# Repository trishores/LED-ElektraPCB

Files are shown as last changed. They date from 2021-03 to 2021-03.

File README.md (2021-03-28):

# ElektraPCB

Kicad Capture/Layout project files for the Elektra LED development board.

**Licensing info**

Copyright 2018-2021 ledmaker.org

ElektraPCB is free software: you can redistribute it and/or modify it under the terms of the GNU General Public License as published by the Free Software Foundation, either version 3 of the License, or any later version.

ElektraPCB is distributed in the hope that it will be useful, but WITHOUT ANY WARRANTY; without even the implied warranty of MERCHANTABILITY or FITNESS FOR A PARTICULAR PURPOSE. See the GNU General Public License for more details.

You should have received a copy of the GNU General Public License along with ElektraPCB. If not, see https://www.gnu.org/licenses/.

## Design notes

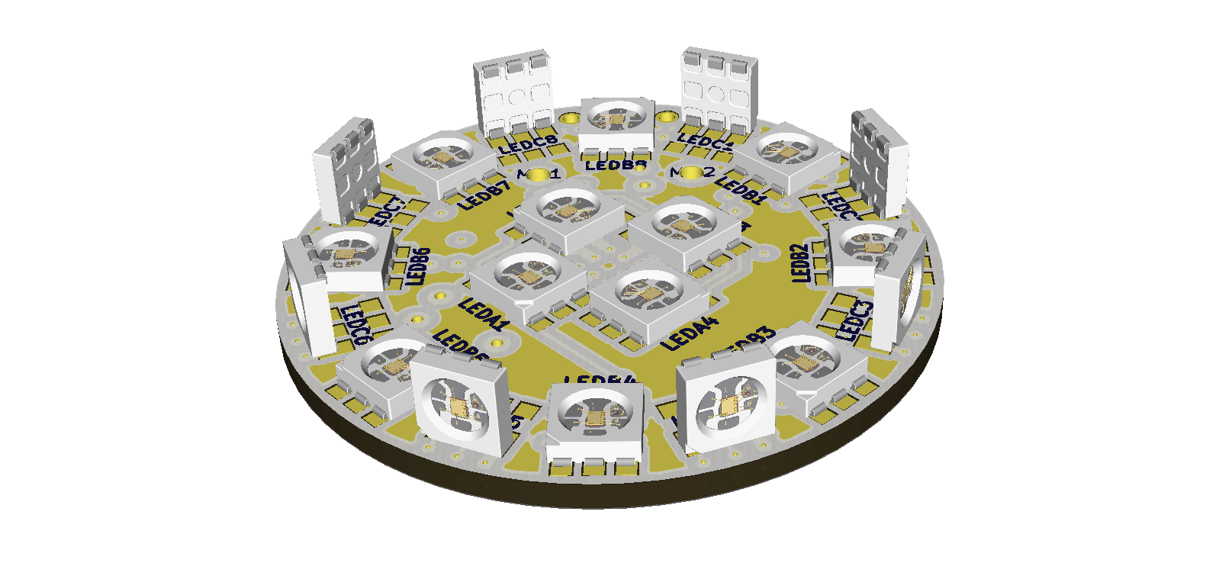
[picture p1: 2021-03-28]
Kicad/disc-front.png

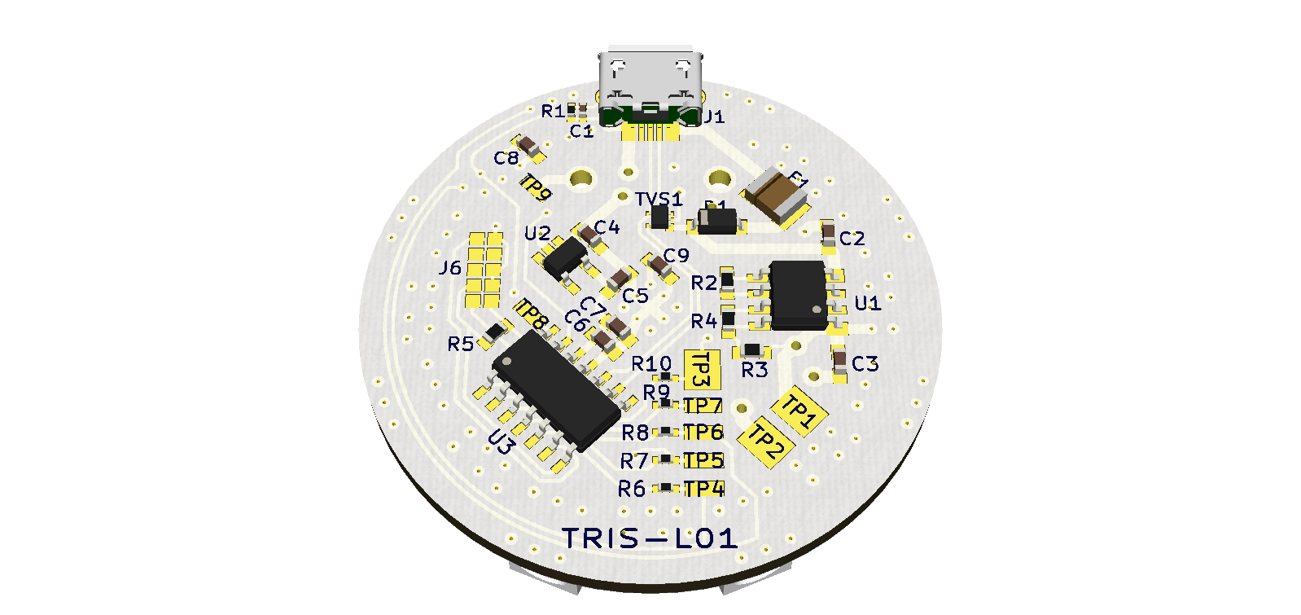
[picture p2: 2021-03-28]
Kicad/disc-back.png

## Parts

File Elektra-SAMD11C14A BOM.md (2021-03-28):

# Elektra-SAMD11C14A development board parts list

| PCB part designators | Quantity | Digikey PN | Manufacturer PN |
| ---| --- | --- | --- |
| J1 | 1 | 609-4616-1-ND | 10118193-0001LF |
| D2 | 1 | SMA6J11AHR3GCT-ND | SMA6J11AHR3G |
| F1 | 1 | 507-1787-1-ND | 0ZCH0075FF2G |
| D1 | 1 | APD240KDTR-G1DICT-ND | APD240KDTR-G1 |
| TVS1 | 1 | NUP2114UPXV5T1GOSCT-ND | NUP2114UPXV5T1G |
| C1* | 1 | 311-1680-1-ND | CC0402JRX7R9BB472 |
| R1* | 1 | 311-1.00MLRCT-ND | RC0402FR-071ML |
| U1 | 1 | 497-17854-1-ND | LDL212DR |
| C2, C3, C4, C5, C7, C8, C9 | 7 | 587-1785-1-ND | JMK107BJ475KA-T |
| R4 | 1 | RR08P22.0KDCT-ND | RR0816P-223-D |
| R2, R3 | 2 | RR08P62.0KDCT-ND | RR0816P-623-D |
| U2 | 1 | MCP1754T-3302E/OTCT-ND | MCP1754T-3302E/OT |
| LEDxx | 20 | - | APA102C** |
| U3 | 1 | ATSAMD11C14A-SSUT | ATSAMD11C14A-SSUT |
| C6 | 1 | 311-1338-1-ND | CC0402KRX7R7BB104 |
| R5 | 1 | 311-1.00KLRCT-ND | RC0402FR-071KL |
| R6, R7, R8, R9, R10 | 5 | P330LCT-ND | ERJ-2RKF3300X |
| J2 | 1 | 952-3577-ND | M50-3030542 |
| Programmer/Debugger | 1 | ATATMEL-ICE-BASIC-ND | ATATMEL-ICE-BASIC |

\* Optional for added protection against noise and transients.

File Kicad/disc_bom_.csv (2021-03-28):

Part | References | Value | Footprint | Quantity
1276-1444-1-ND | C10 | 1uF | C_0402_HandSoldering | 1
311-1.00KLRCT-ND | R5 | 1K | R_0603_HandSoldering | 1
311-1338-1-ND | C6 C11 | 100nF | C_0402_HandSoldering | 2
497-17854-1-ND | U1 | ~ | SOIC-8-LARGE-PADS | 1
507-1787-1-ND | F1 | ~ | F_1210_HandSoldering | 1
587-1785-1-ND | C2 C3 C4 C5 C7 C8 C9 | 4.7uF | C_0603_HandSoldering | 7
609-4616-1-ND | J1 | ~ | USB_Micro_10118193-0001LF-NOPADS | 1
APD240KDTR-G1DICT-ND | D1 | ~ | D_SOD-123 | 1
ATSAMD21E17A-AUTCT-ND | U3 | ATSAMD21E | TQFP-32_7x7mm | 1
952-3577-ND | M50-3030542 | CONN-1x5 | CONN-050-1x5-TH | 1
MCP1754T-3302E/OTCT-ND | U2 | ~ | SOT-23-5_HandSoldering | 1
NUP2114UPXV5T1GOSCT-ND | TVS1 | ~ | SOT-553-LARGE-PADS | 1
P330LCT-ND | R6 R7 R8 R9 R10 | 330 | R_0402_HandSoldering | 5
RR08P22.0KDCT-ND | R4 | 22K | R_0603_HandSoldering | 1
RR08P62.0KDCT-ND | R2 R3 | 62K | R_0603_HandSoldering | 2
SMA6J11AHR3GCT-ND | D2 | SMA6J11A | DO214AC | 1

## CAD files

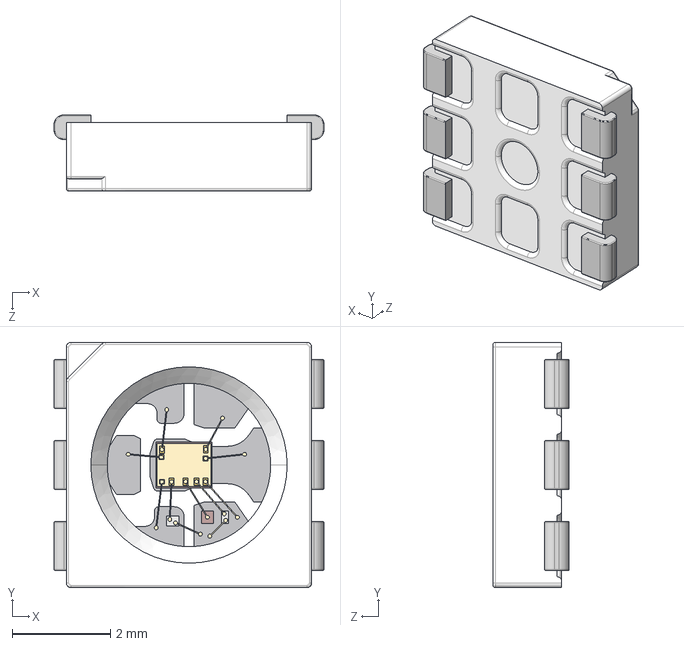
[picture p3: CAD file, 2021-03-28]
a-3d-models/disc-3d/5050/5050.STEP
5.50 x 5.00 x 1.55 mm

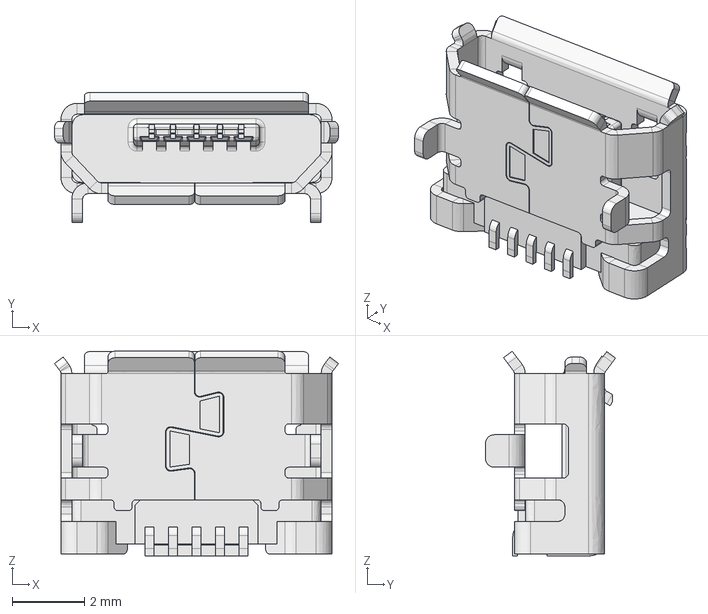
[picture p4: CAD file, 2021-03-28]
a-3d-models/disc-3d/USB_10118193-0001LF/USB_Micro2.FCStd
7.86 x 3.60 x 5.66 mm

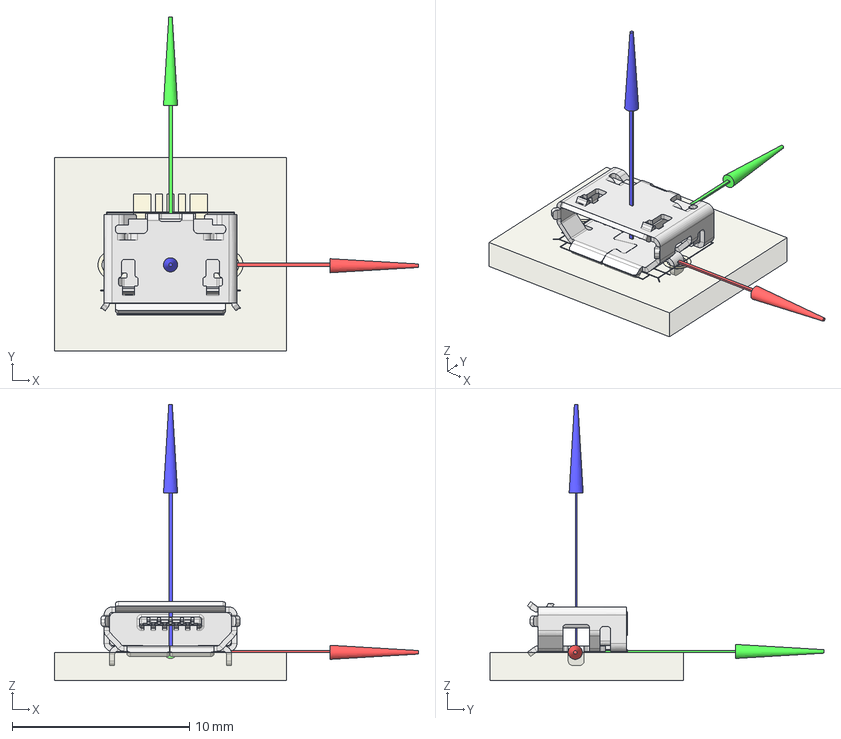
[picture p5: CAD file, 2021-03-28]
a-3d-models/disc-3d/USB_10118193-0001LF/usb_micro.FCStd
20.6 x 18.9 x 15.6 mm
FCrtYd
FFab
TopPads
BotPads
PTHs
Pcb
Z
Y
X
A4A0504-MODIFY-1106_ASM

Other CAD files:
a-3d-models/disc-3d/5050/5050-RA.step
a-3d-models/disc-3d/USB_10118193-0001LF/USB_Micro.stl

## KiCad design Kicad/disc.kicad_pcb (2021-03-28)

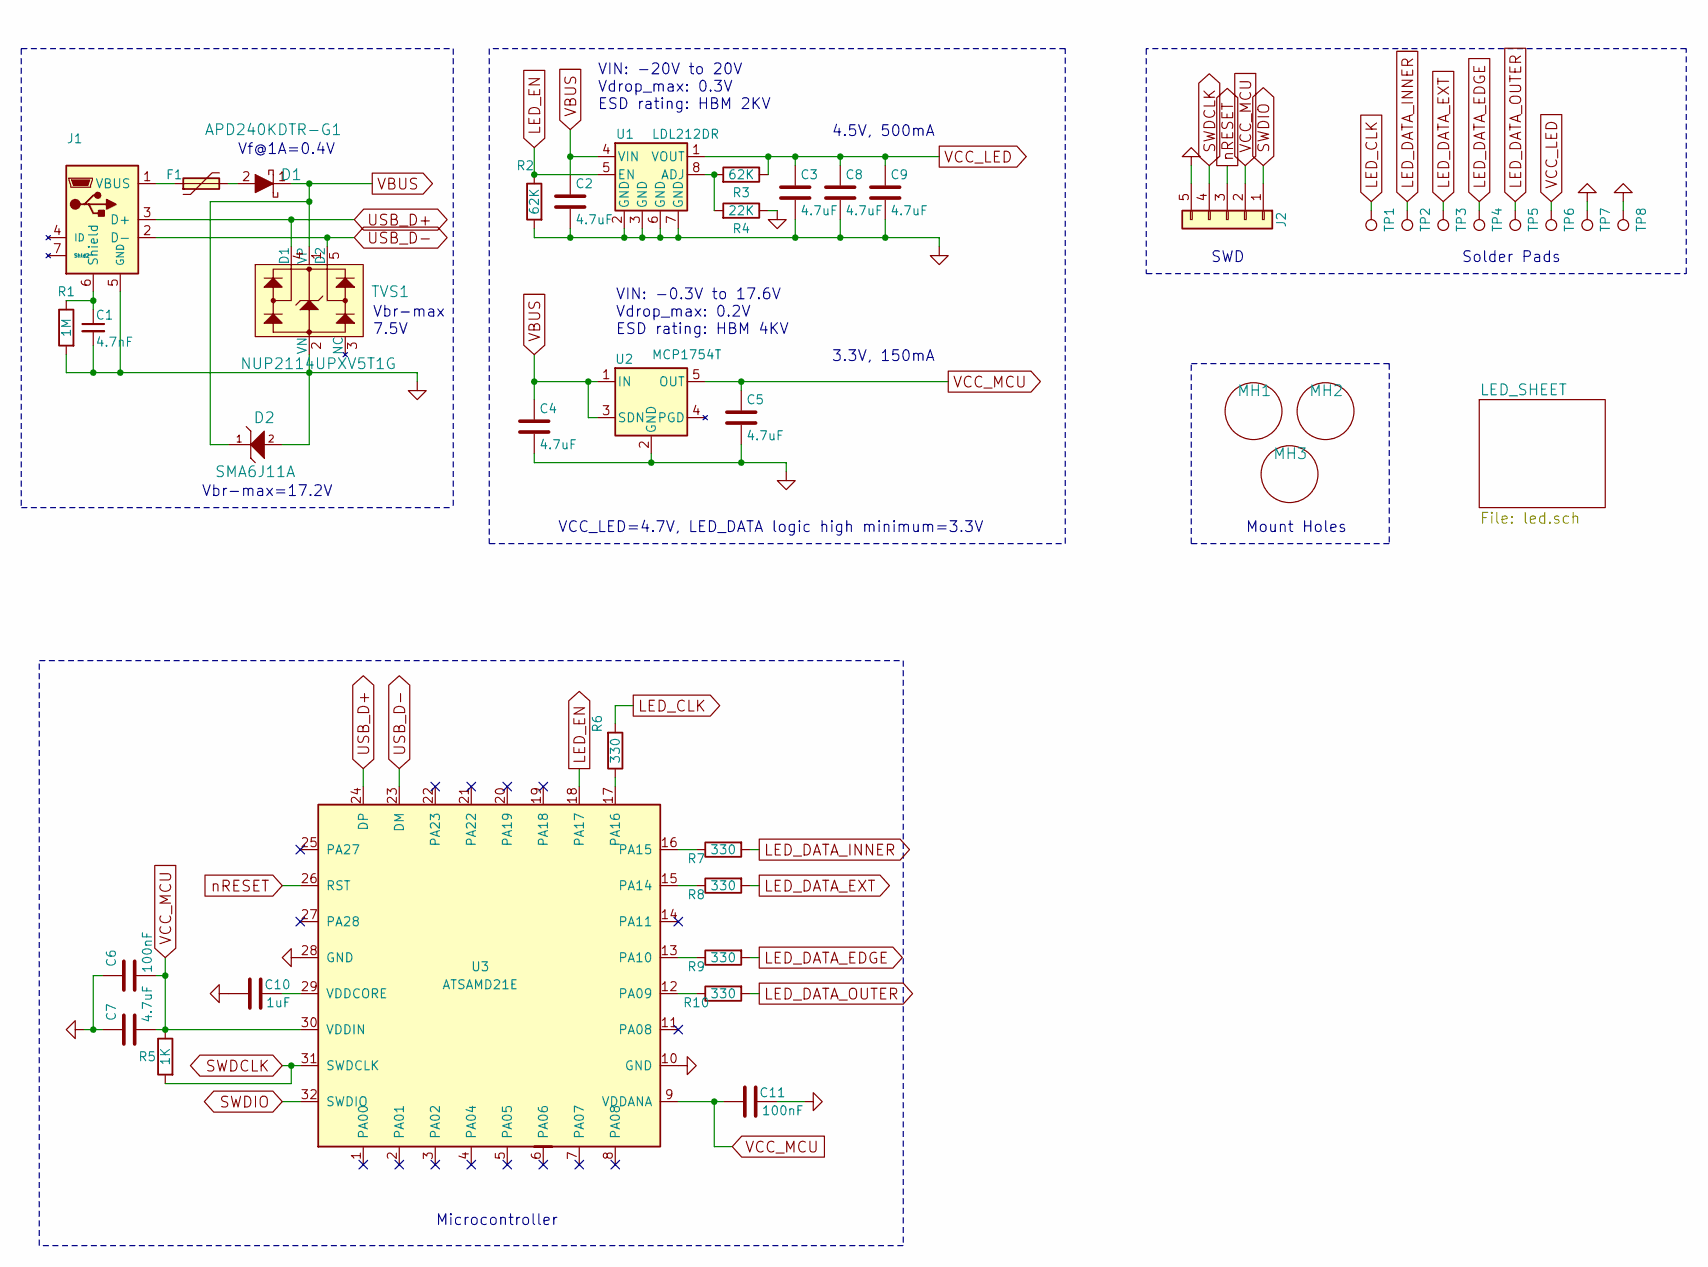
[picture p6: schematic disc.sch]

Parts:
C1: 4.7nF; C_0402-HandSoldering
C2, C3, C4, C5, C7, C8, C9: 4.7uF; C_0603_HandSoldering
C6, C11: 100nF; C_0402_HandSoldering
C10: 1uF; C_0402_HandSoldering
D1: APD240KDTR-G1; D_SOD-123
D2: SMA6J11A; DO214AC
F1: F_1210_HandSoldering
J1: USB_Micro_10118193-0001LF-NOPADS
J2: CONN-1x5; CONN-050-1x5-TH
MH1, MH2, MH3: Hole-3-64
R1: 1M; R_0402_HandSoldering
R2, R3: 62K; R_0603_HandSoldering
R4: 22K; R_0603_HandSoldering
R5: 1K; R_0603_HandSoldering
R6, R7, R8, R9, R10: 330; R_0402_HandSoldering
TP1, TP6, TP7, TP8: Conn-pad; SOLDER-PAD
TP2, TP3, TP4, TP5: Conn-pad; SOLDER-PAD-SLIM
TVS1: NUP2114UPXV5T1G; SOT-553-LARGE-PADS
U1: LDL212DR; SOIC-8-LARGE-PADS
U2: MCP1754T; SOT-23-5_HandSoldering
U3: ATSAMD21E; TQFP-32_7x7mm

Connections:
GND: C1.2, C2.2, C3.2, C4.2, C5.2, C6.2, C7.2, C8.2, C9.2, C10.1, C11.2, D2.2, J1.5 (GND), J2.5, R1.2, R2.2, R4.1, TP7.1, TP8.1, TVS1.2 (VN), U1.2 (GND), U1.3 (GND), U1.6 (GND), U1.7 (GND), U2.2 (GND), U3.10 (GND), U3.28 (GND); also elsewhere on the board
LED_CLK: R6.2, TP1.1; also elsewhere on the board
LED_DATA_EDGE: R9.2, TP4.1; also elsewhere on the board
LED_DATA_EXT: R8.2, TP3.1
LED_DATA_INNER: R7.2, TP2.1; also elsewhere on the board
LED_DATA_OUTER: R10.2, TP5.1; also elsewhere on the board
LED_EN: R2.1, U1.5 (EN), U3.18 (PA17)
unnamed: C1.1, J1.6 (Shield), R1.1
unnamed: C10.2, U3.29 (VDDCORE)
unnamed: D1.2, F1.2
unnamed: F1.1, J1.1 (VBUS)
unnamed: R3.2, R4.2, U1.8 (ADJ)
unnamed: R6.1, U3.17 (PA16)
unnamed: R7.1, U3.16 (PA15)
unnamed: R8.1, U3.15 (PA14)
unnamed: R9.1, U3.13 (PA10)
unnamed: R10.1, U3.12 (PA09)
SWDCLK: J2.4, R5.2, U3.31 (SWDCLK)
SWDIO: J2.1, U3.32 (SWDIO)
USB_D+: J1.3 (D+), TVS1.4 (D1), U3.24 (DP)
USB_D-: J1.2 (D-), TVS1.5 (D2), U3.23 (DM)
VBUS: C2.1, C4.1, D1.1, D2.1, TVS1.1 (VP), U1.4 (VIN), U2.1 (IN), U2.3 (SDN)
VCC_LED: C3.1, C8.1, C9.1, R3.1, TP6.1, U1.1 (VOUT); also elsewhere on the board
VCC_MCU: C5.1, C6.1, C7.1, C11.1, J2.2, R5.1, U2.5 (OUT), U3.9 (VDDANA), U3.30 (VDDIN)
nRESET: J2.3, U3.26 (RST)

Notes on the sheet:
4.5V, 500mA
VIN: -20V to 20V Vdrop_max: 0.3V ESD rating: HBM 2KV
3.3V, 150mA
Vf@1A=0.4V
VIN: -0.3V to 17.6V Vdrop_max: 0.2V ESD rating: HBM 4KV
SWD
VCC_LED=4.7V, LED_DATA logic high minimum=3.3V
Solder Pads
Mount Holes
Vbr-max=17.2V
Vbr-max 7.5V
Microcontroller

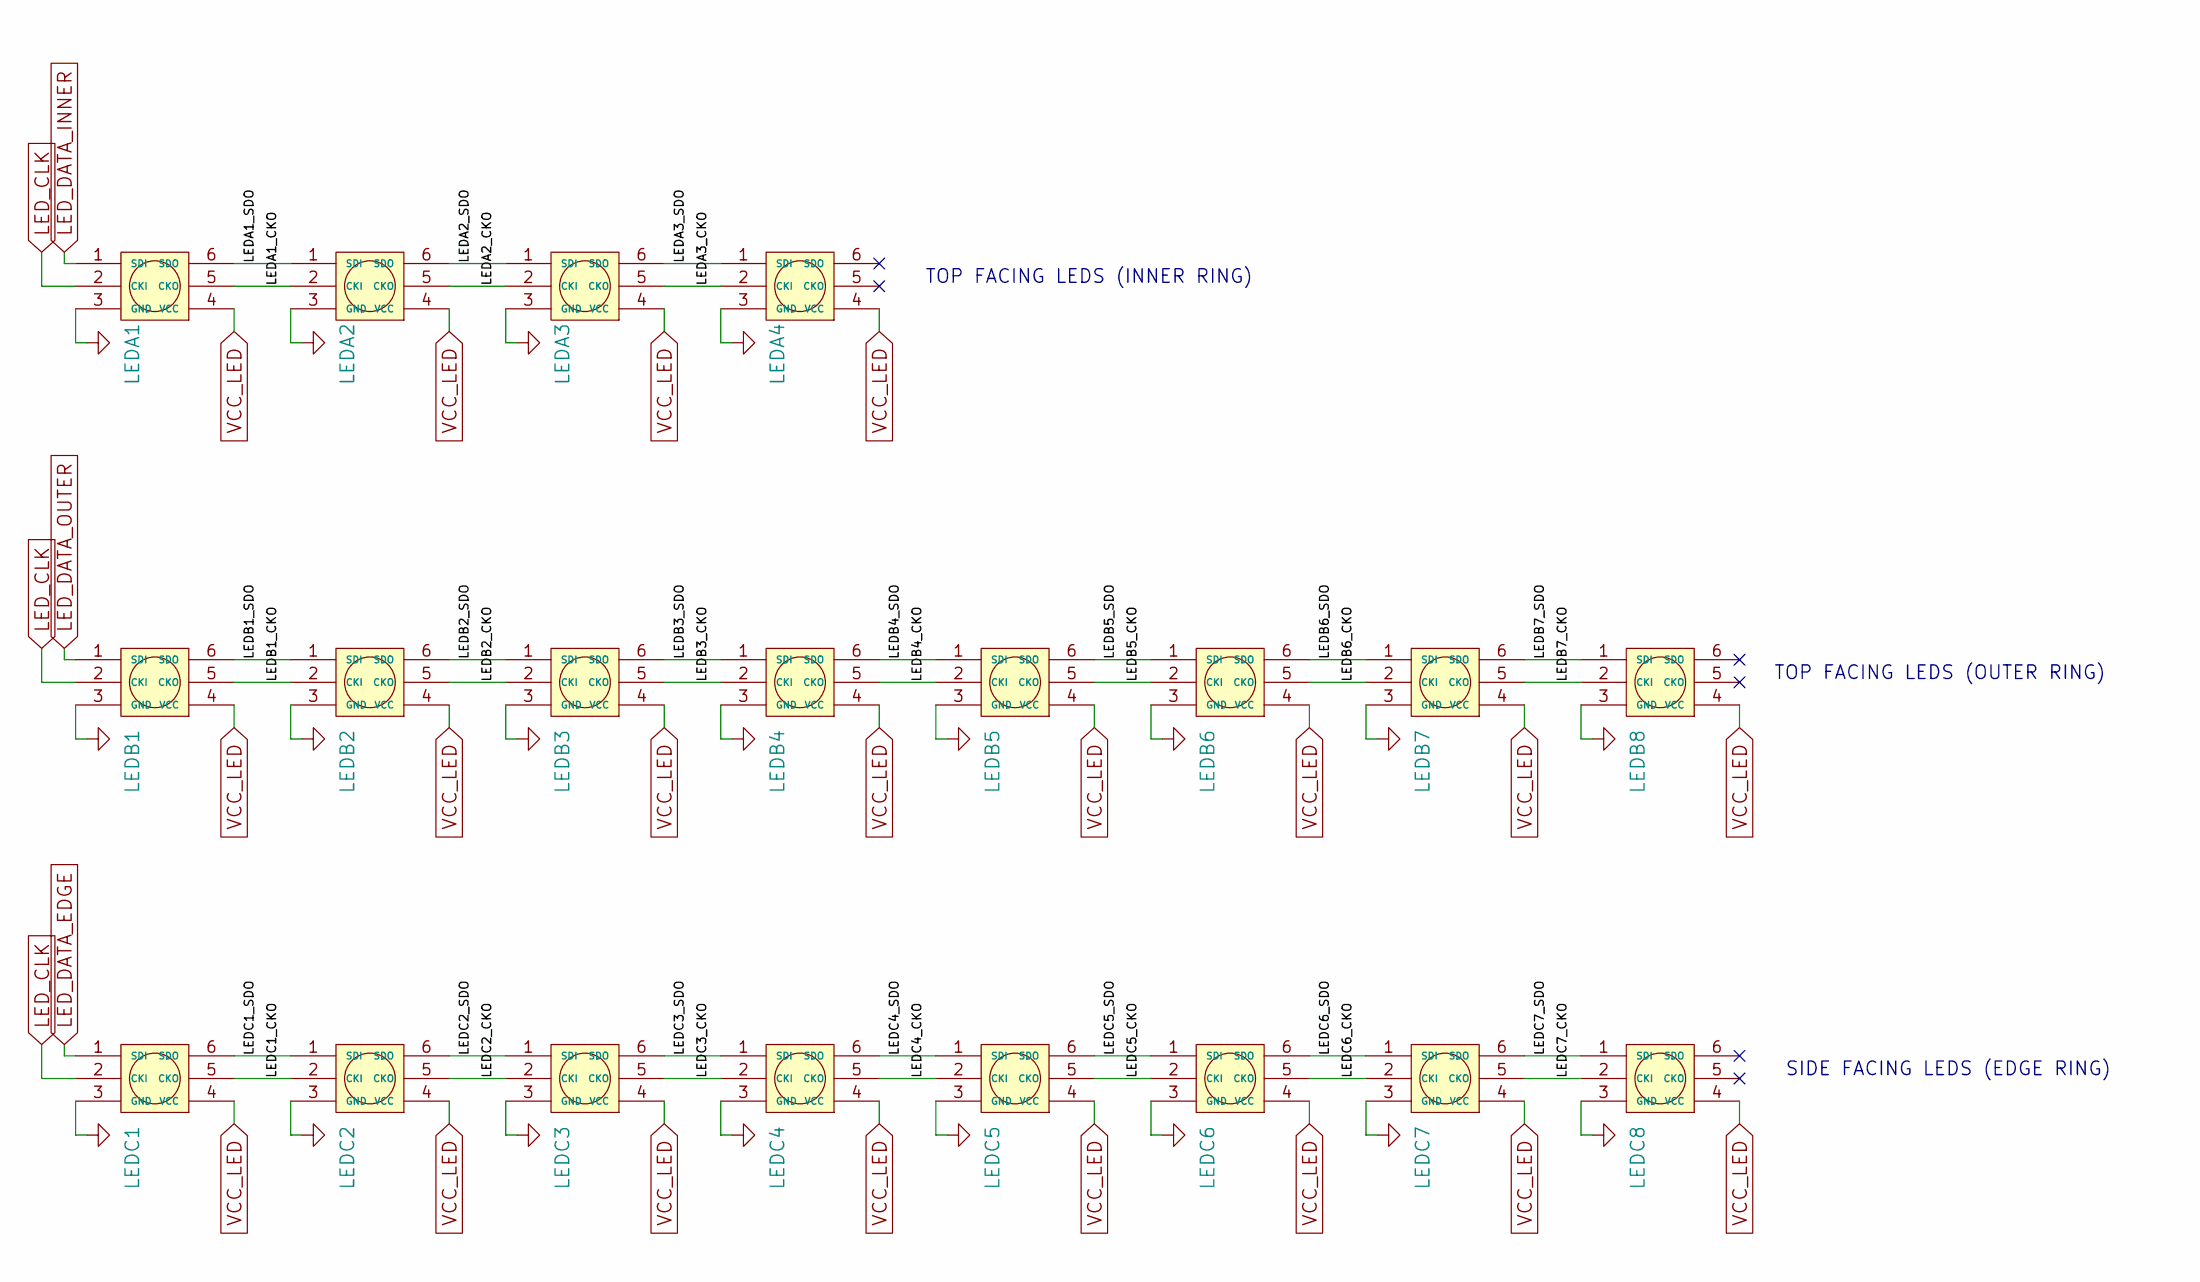
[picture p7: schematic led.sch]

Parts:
LEDA1, LEDA2, LEDA3, LEDA4: 5050-6
LEDB1, LEDB2, LEDB3, LEDB4, LEDB5, LEDB6, LEDB7, LEDB8: 5050-6
LEDC1, LEDC2, LEDC3, LEDC4, LEDC5, LEDC6, LEDC7, LEDC8: 5050-6-RA

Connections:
/LED_SHEET/LEDA1_CKO: LEDA1.5 (CKO), LEDA2.2 (CKI)
/LED_SHEET/LEDA1_SDO: LEDA1.6 (SDO), LEDA2.1 (SDI)
/LED_SHEET/LEDA2_CKO: LEDA2.5 (CKO), LEDA3.2 (CKI)
/LED_SHEET/LEDA2_SDO: LEDA2.6 (SDO), LEDA3.1 (SDI)
/LED_SHEET/LEDA3_CKO: LEDA3.5 (CKO), LEDA4.2 (CKI)
/LED_SHEET/LEDA3_SDO: LEDA3.6 (SDO), LEDA4.1 (SDI)
/LED_SHEET/LEDB1_CKO: LEDB1.5 (CKO), LEDB2.2 (CKI)
/LED_SHEET/LEDB1_SDO: LEDB1.6 (SDO), LEDB2.1 (SDI)
/LED_SHEET/LEDB2_CKO: LEDB2.5 (CKO), LEDB3.2 (CKI)
/LED_SHEET/LEDB2_SDO: LEDB2.6 (SDO), LEDB3.1 (SDI)
/LED_SHEET/LEDB3_CKO: LEDB3.5 (CKO), LEDB4.2 (CKI)
/LED_SHEET/LEDB3_SDO: LEDB3.6 (SDO), LEDB4.1 (SDI)
/LED_SHEET/LEDB4_CKO: LEDB4.5 (CKO), LEDB5.2 (CKI)
/LED_SHEET/LEDB4_SDO: LEDB4.6 (SDO), LEDB5.1 (SDI)
/LED_SHEET/LEDB5_CKO: LEDB5.5 (CKO), LEDB6.2 (CKI)
/LED_SHEET/LEDB5_SDO: LEDB5.6 (SDO), LEDB6.1 (SDI)
/LED_SHEET/LEDB6_CKO: LEDB6.5 (CKO), LEDB7.2 (CKI)
/LED_SHEET/LEDB6_SDO: LEDB6.6 (SDO), LEDB7.1 (SDI)
/LED_SHEET/LEDB7_CKO: LEDB7.5 (CKO), LEDB8.2 (CKI)
/LED_SHEET/LEDB7_SDO: LEDB7.6 (SDO), LEDB8.1 (SDI)
/LED_SHEET/LEDC1_CKO: LEDC1.5 (CKO), LEDC2.2 (CKI)
/LED_SHEET/LEDC1_SDO: LEDC1.6 (SDO), LEDC2.1 (SDI)
/LED_SHEET/LEDC2_CKO: LEDC2.5 (CKO), LEDC3.2 (CKI)
/LED_SHEET/LEDC2_SDO: LEDC2.6 (SDO), LEDC3.1 (SDI)
/LED_SHEET/LEDC3_CKO: LEDC3.5 (CKO), LEDC4.2 (CKI)
/LED_SHEET/LEDC3_SDO: LEDC3.6 (SDO), LEDC4.1 (SDI)
/LED_SHEET/LEDC4_CKO: LEDC4.5 (CKO), LEDC5.2 (CKI)
/LED_SHEET/LEDC4_SDO: LEDC4.6 (SDO), LEDC5.1 (SDI)
/LED_SHEET/LEDC5_CKO: LEDC5.5 (CKO), LEDC6.2 (CKI)
/LED_SHEET/LEDC5_SDO: LEDC5.6 (SDO), LEDC6.1 (SDI)
/LED_SHEET/LEDC6_CKO: LEDC6.5 (CKO), LEDC7.2 (CKI)
/LED_SHEET/LEDC6_SDO: LEDC6.6 (SDO), LEDC7.1 (SDI)
/LED_SHEET/LEDC7_CKO: LEDC7.5 (CKO), LEDC8.2 (CKI)
/LED_SHEET/LEDC7_SDO: LEDC7.6 (SDO), LEDC8.1 (SDI)
GND: LEDA1.3 (GND), LEDA2.3 (GND), LEDA3.3 (GND), LEDA4.3 (GND), LEDB1.3 (GND), LEDB2.3 (GND), LEDB3.3 (GND), LEDB4.3 (GND), LEDB5.3 (GND), LEDB6.3 (GND), LEDB7.3 (GND), LEDB8.3 (GND), LEDC1.3 (GND), LEDC2.3 (GND), LEDC3.3 (GND), LEDC4.3 (GND), LEDC5.3 (GND), LEDC6.3 (GND), LEDC7.3 (GND), LEDC8.3 (GND); also elsewhere on the board
LED_CLK: LEDA1.2 (CKI), LEDB1.2 (CKI), LEDC1.2 (CKI); also elsewhere on the board
LED_DATA_EDGE: LEDC1.1 (SDI); also elsewhere on the board
LED_DATA_INNER: LEDA1.1 (SDI); also elsewhere on the board
LED_DATA_OUTER: LEDB1.1 (SDI); also elsewhere on the board
VCC_LED: LEDA1.4 (VCC), LEDA2.4 (VCC), LEDA3.4 (VCC), LEDA4.4 (VCC), LEDB1.4 (VCC), LEDB2.4 (VCC), LEDB3.4 (VCC), LEDB4.4 (VCC), LEDB5.4 (VCC), LEDB6.4 (VCC), LEDB7.4 (VCC), LEDB8.4 (VCC), LEDC1.4 (VCC), LEDC2.4 (VCC), LEDC3.4 (VCC), LEDC4.4 (VCC), LEDC5.4 (VCC), LEDC6.4 (VCC), LEDC7.4 (VCC), LEDC8.4 (VCC); also elsewhere on the board

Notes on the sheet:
SIDE FACING LEDS (EDGE RING)
TOP FACING LEDS (OUTER RING)
TOP FACING LEDS (INNER RING)

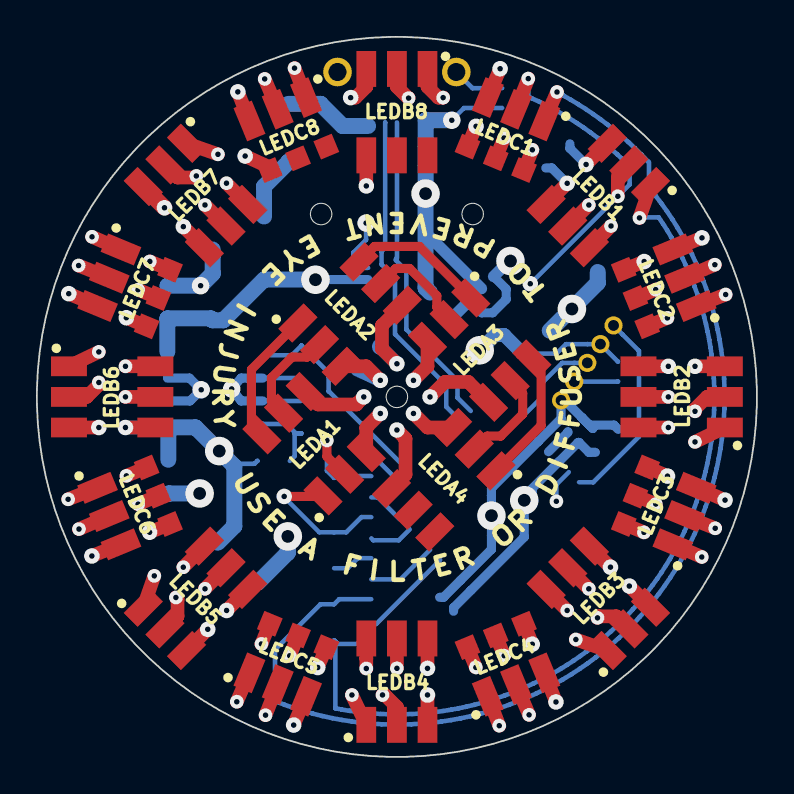
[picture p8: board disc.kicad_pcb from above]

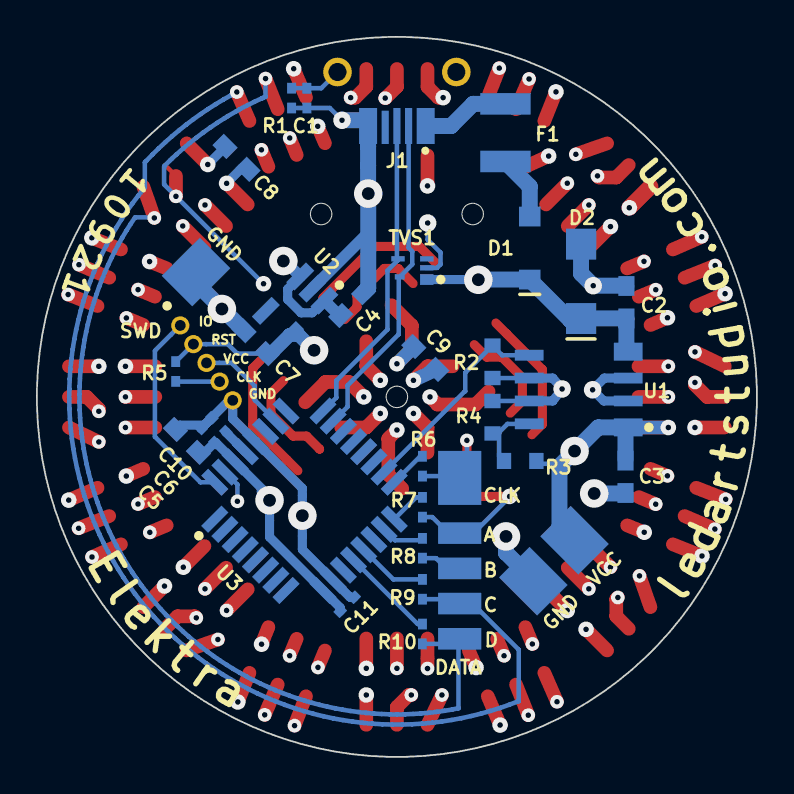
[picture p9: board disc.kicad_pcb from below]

Board: 4 copper layers, 40.0 x 40.0 mm, 61 parts (38 on the bottom side), 59 nets.
